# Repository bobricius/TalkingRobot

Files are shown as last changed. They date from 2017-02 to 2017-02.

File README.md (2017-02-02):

simple children toy robot 

Features 

- max. 44khz, 16bit wav 
- supply voltage 3,3V to 5V can be powered with LIR2032 battery, not CR2032! 
- you can optionally solder mini or micro usb connector 
- dimensions 5 cm x 10 cm 
- upgradeable firmware, AVR AtTiny861 based board 
- 16bit output created from 2 shifted 8bit PWM channels, good quality 
- output for speraker 
- can driving small speaker, amplifier is recommended 
- 8 control signals on header active in low 
- 8 buttons for testing + 2 LED on eyes, 1 LED as heart button (reset) + 8 LED connected to buttons 
- micro SD card push-push connector 

https://www.youtube.com/watch?v=AGjfrQgZr3E

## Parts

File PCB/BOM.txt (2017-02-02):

Partlist

Exported from robotrev2.brd at 2. 2. 2017 22:56

EAGLE Version 7.6.0 Copyright (c) 1988-2016 CadSoft

Assembly variant: 

Part          Value                   Package                 Library                       Position (mil)        Orientation

1                                     TACTILE-SWITCH-1101NE   SparkFun                      (1757.5 281.25)       R180
2                                     TACTILE-SWITCH-1101NE   SparkFun                      (507.5 275)           R180
3                                     TACTILE-SWITCH-1101NE   SparkFun                      (1457.5 1013.75)      R135
3V3           3V3                     SOT23                   okie                          (1145 962.5)          R180
4                                     TACTILE-SWITCH-1101NE   SparkFun                      (807.5 1012.5)        R45
5                                     TACTILE-SWITCH-1101NE   SparkFun                      (1863.75 1837.5)      R270
6                                     TACTILE-SWITCH-1101NE   SparkFun                      (395 1837.5)          R270
7                                     TACTILE-SWITCH-1101NE   SparkFun                      (1757.5 2631.25)      R315
8                                     TACTILE-SWITCH-1101NE   SparkFun                      (507.5 2637.5)        R45
BATTERY                               BATTCOM_20MM_PTH        es                            (1130 2895)           R270
BATTERYENABLE SOLDERJUMPERNO          SJ_2S-NO                SparkFun                      (730 2590)            R180
C1            10uF                    C0603                   rc-master-smd                 (740 2690)            R180
C2            100                     153CLV-0605             resistor                      (1128.75 3808.75)     R270
C3            10uF                    C0603                   rc-master-smd                 (1030 2870)           R270
C4            100n                    C0603                   rc-master-smd                 (1282.5 981.25)       R90
C5            100n                    C0603                   rc-master-smd                 (1001.25 975)         R270
C6            100n                    C0603                   rc-master-smd                 (1410 1595)           R270
C7            100n                    C0603                   rc-master-smd                 (855 1595)            R90
CHARGER                               SML0603                 led                           (920 2850)            R0
IC1           74HCT14D                SO14                    74xx-eu                       (1129 3430)           R180
IC2           MCP73831                SOT23-5                 SparkFunNew                   (745 2825)            R90
JP1                                   1X02                    pinhead                       (1470 2000)           MR270
JP2                                   1X02                    pinhead                       (795 1995)            R270
JP3                                   1X09                    pinhead                       (1130 1595)           MR270
JP5                                   1X02                    pinhead                       (620 3650)            R90
JP6                                   1X02                    pinhead                       (1645 3650)           R270
L1                                    SML0603                 led                           (1595 450)            R0
L2                                    SML0603                 led                           (670 450)             R0
L3                                    SML0603                 led                           (2020 250)            R0
L4                                    SML0603                 led                           (245 250)             R0
L5                                    SML0603                 led                           (1745 1425)           R0
L6                                    SML0603                 led                           (520 1425)            R0
L7                                    SML0603                 led                           (1995 1425)           R0
L8                                    SML0603                 led                           (270 1425)            R0
LEDCH         1k                      R0603                   rcl                           (905 2790)            R180
PB1                                   SML0603                 led                           (1391.25 3793.75)     R0
PB3                                   SML0603                 led                           (885 3800)            R0
PLAY2                                 SML0603                 led                           (1130 2820)           R0
R1            1k                      R0603                   resistor                      (1470 2650)           R270
R2            1k                      R0603                   resistor                      (1391.25 3925)        R180
R3            1k                      R0603                   resistor                      (1695 450)            R90
R4            1k                      R0603                   resistor                      (885 3925)            R0
R5            1k                      R0603                   resistor                      (570 450)             R90
R6            256k                    R0603                   resistor                      (1424 3425)           R45
R7            1k                      R0603                   resistor                      (1770 450)            R90
R8            1k                      R0603                   resistor                      (495 450)             R90
R9            1k                      R0603                   resistor                      (1745 1550)           R90
R10           1k                      R0603                   resistor                      (520 1550)            R90
R11           1k                      R0603                   resistor                      (1995 1550)           R90
R12           1k                      R0603                   resistor                      (270 1550)            R90
R13           1k                      R0603                   resistor                      (1389 3510)           R45
R14           200                     R0603                   resistor                      (824 3425)            R135
R15           56                      R0603                   resistor                      (859 3510)            R315
RPROG         22K                     R0603                   rcl                           (595 2825)            R0
S1            SWITCH-MOMENTARY-LEDPTH TACTILE-PTH-LED-12MM    Local Library                 (1130 2495)           R90
U$1           AVR_SPI_PRG_6NS         2X3-NS                  SparkFun                      (1132.75 2488.75)     MR180
U$3           MOUNTINGHOLE2.0         MOUNTINGHOLE_2.0_PLATED microbuilder                  (1901.25 2125)        R0
U$4           MOUNTINGHOLE2.0         MOUNTINGHOLE_2.0_PLATED microbuilder                  (363.75 2125)         R0
U$6           MOUNTINGHOLE2.0         MOUNTINGHOLE_2.0_PLATED microbuilder                  (588.75 706.25)       R0
U$7           MOUNTINGHOLE2.0         MOUNTINGHOLE_2.0_PLATED microbuilder                  (1676.25 706.25)      R0
U$9           MICROSD_PP              MICROSD_PP              DE1594-v2                     (1114.75 3326.5)      MR90
U1            ATTINY861A-SU           SOIC127P1032X265-20N    Atmel_By_element14_Batch_1-00 (1131.25 1595)        R0
USB1          USB-MICROBLARGEPAD      USB-MICROB_LARGEPAD     zak                           (1773 2665)           MR225
X5            USBSMD                  USB-MINIB               SparkFun                      (520 2595)            MR223

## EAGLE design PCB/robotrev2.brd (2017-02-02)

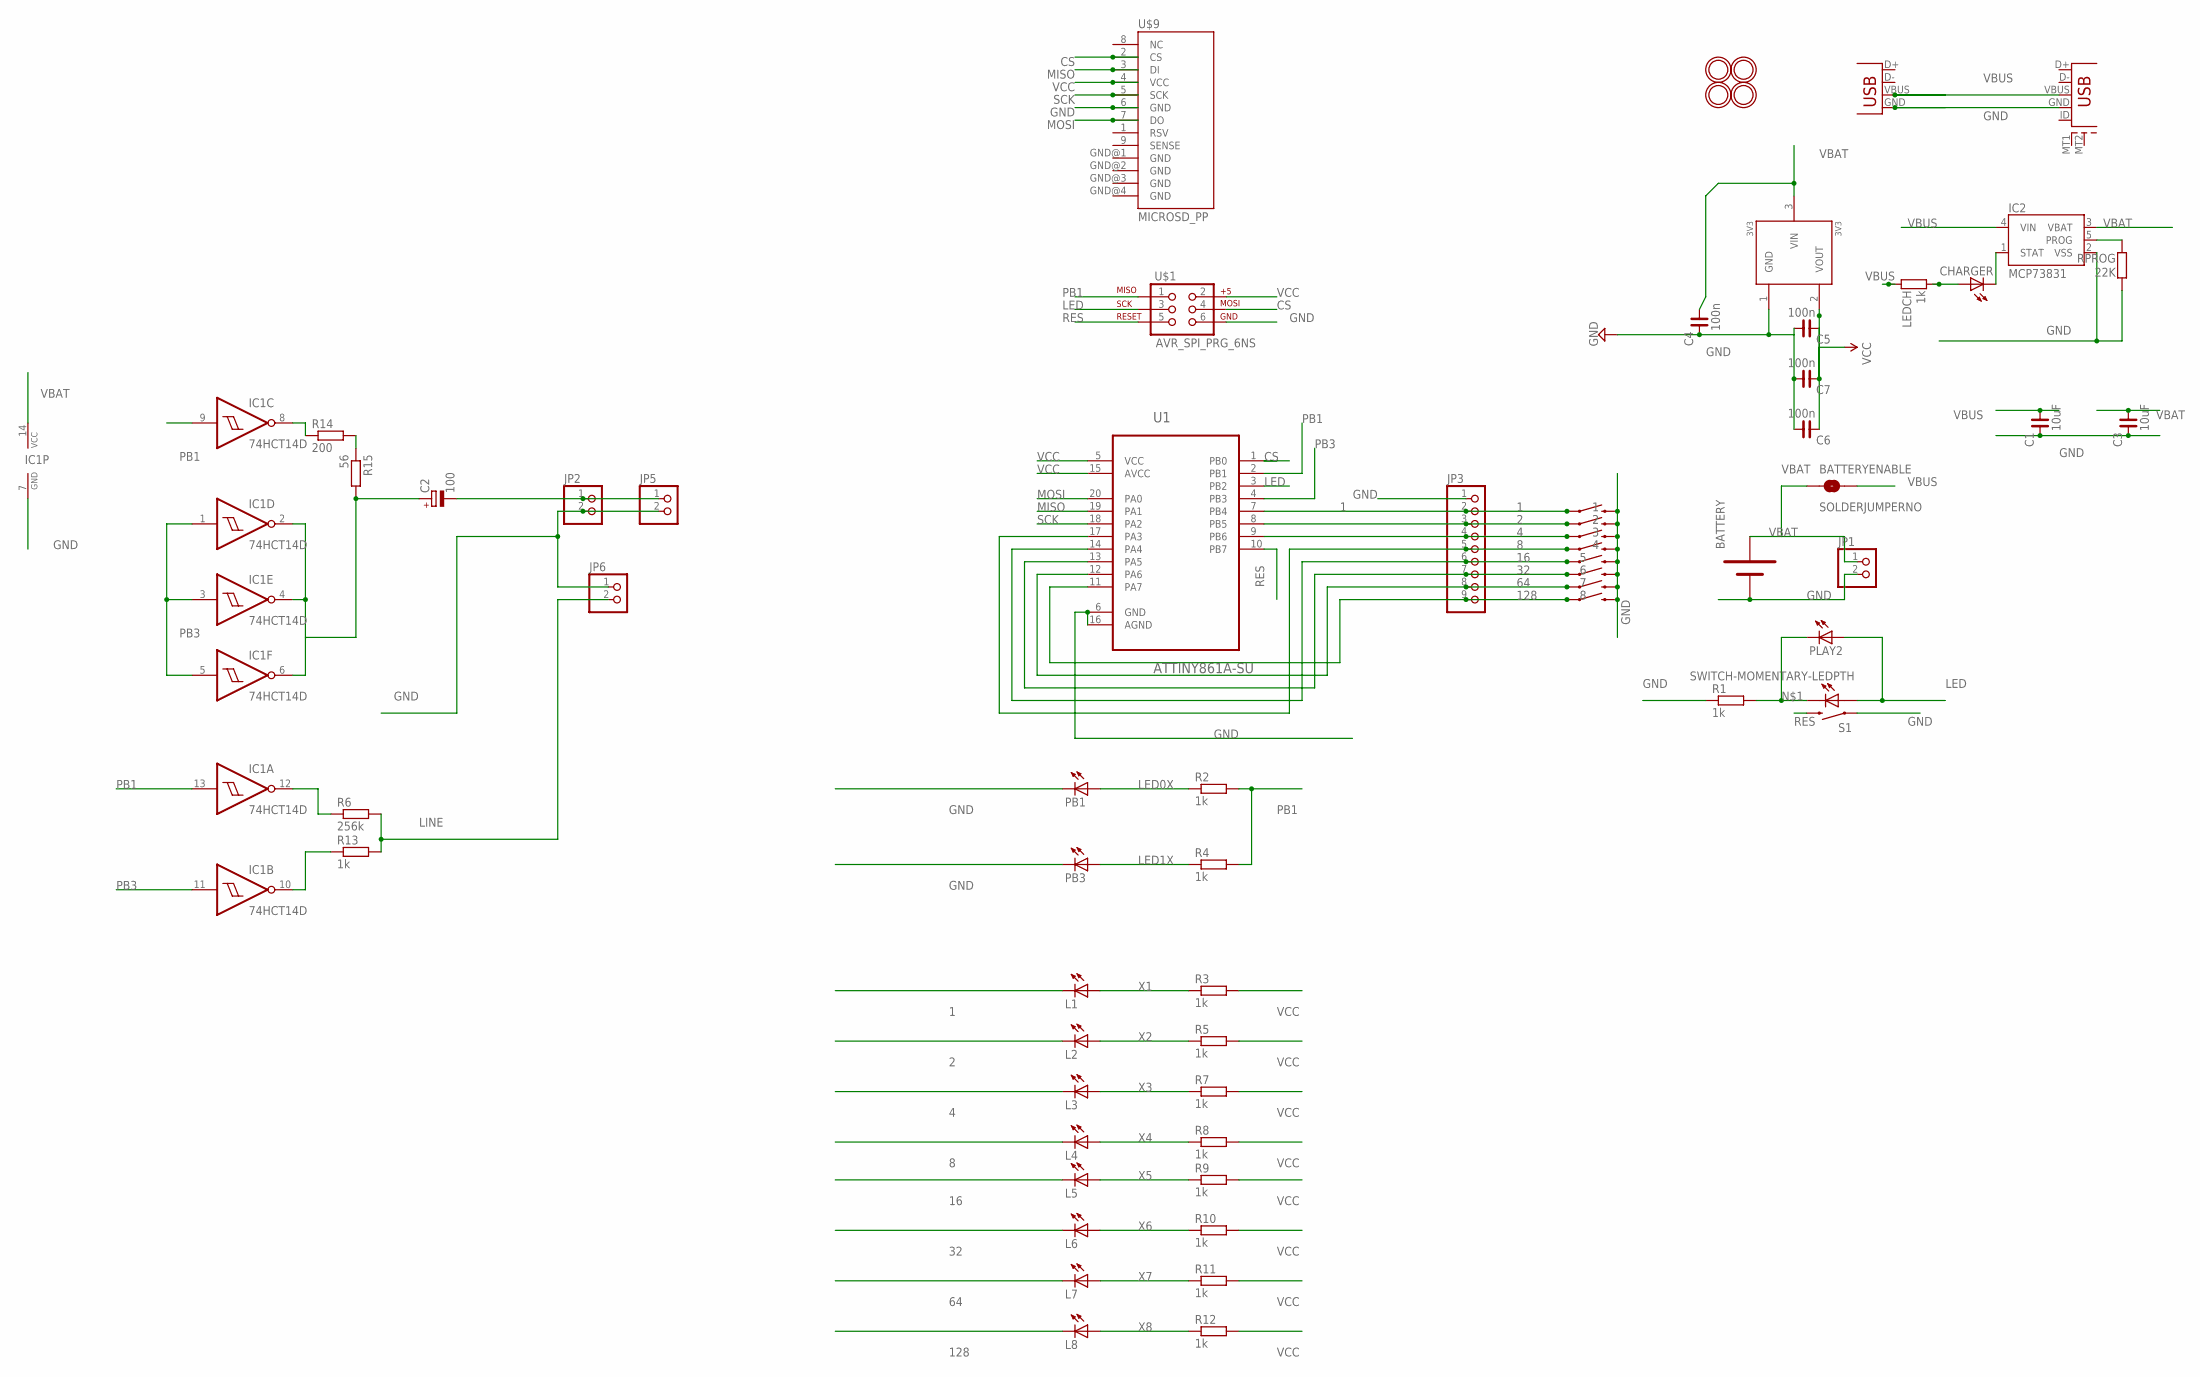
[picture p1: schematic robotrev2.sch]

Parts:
1, 2, 3, 4, 5, 6, 7, 8: SWITCH-MOMENTARY-2-SMD-1101NE; TACTILE-SWITCH-1101NE
3V3: 3V3; SOT23
BATTERY: BATTERY-1XAA20MM; BATTCOM_20MM_PTH
BATTERYENABLE: SOLDERJUMPERNO; SJ_2S-NO
C1, C3: 10uF; C0603
C2: 100; 153CLV-0605
C4, C5, C6, C7: 100n; C0603
CHARGER: LEDSML0603; SML0603
IC1: 74HCT14D; SO14
IC2: MCP73831; SOT23-5
JP1, JP2, JP5, JP6: PINHD-1X2; 1X02
JP3: PINHD-1X9; 1X09
L1, L2, L3, L4, L5, L6, L7, L8: LEDSML0603; SML0603
LEDCH: 1k; R0603
PB1, PB3: LEDSML0603; SML0603
PLAY2: LEDSML0603; SML0603
R1, R2, R3, R4, R5, R7, R8, R9, R10, R11, R12, R13: 1k; R0603
R6: 256k; R0603
R14: 200; R0603
R15: 56; R0603
RPROG: 22K; R0603
S1: SWITCH-MOMENTARY-LEDPTH; TACTILE-PTH-LED-12MM
U1: ATTINY861A-SU; SOIC127P1032X265-20N
U$1: AVR_SPI_PRG_6NS; 2X3-NS
U$3, U$4, U$6, U$7: MOUNTINGHOLE2.0; MOUNTINGHOLE_2.0_PLATED
U$9: MICROSD_PP
USB1: USB-MICROBLARGEPAD; USB-MICROB_LARGEPAD
X5: USBSMD; USB-MINIB

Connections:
1: 1.P$1 (1), JP3.2, L1.C, U1.7 (PB4)
2: 2.P$1 (1), JP3.3, L2.C, U1.8 (PB5)
4: 3.P$1 (1), JP3.4, L3.C, U1.9 (PB6)
8: 4.P$1 (1), JP3.5, L4.C, U1.17 (PA3)
16: 5.P$1 (1), JP3.6, L5.C, U1.14 (PA4)
32: 6.P$1 (1), JP3.7, L6.C, U1.13 (PA5)
64: 7.P$1 (1), JP3.8, L7.C, U1.12 (PA6)
128: 8.P$1 (1), JP3.9, L8.C, U1.11 (PA7)
CS: U1.1 (PB0), U$1.4, U$9.2 (CS)
GND: 1.P$2 (2), 2.P$2 (2), 3.P$2 (2), 3V3.1 (GND), 4.P$2 (2), 5.P$2 (2), 6.P$2 (2), 7.P$2 (2), 8.P$2 (2), BATTERY.-, C1.2, C3.2, C4.2, C5.1, C6.1, C7.1, IC1.7 (GND), IC2.2 (VSS), JP1.2, JP2.2, JP3.1, JP5.2, JP6.1, PB1.C, PB3.C, R1.1, RPROG.1, S1.4 (1), U1.6 (GND), U1.16 (AGND), U$1.6, U$9.6 (GND), USB1.GND, X5.GND
LED: PLAY2.A, S1.A, U1.3 (PB2), U$1.3
LED0X: PB1.A, R2.1
LED1X: PB3.A, R4.1
LINE: JP6.2, R6.2, R13.2
MISO: U1.19 (PA1), U$9.3 (DI)
MOSI: U1.20 (PA0), U$9.7 (DO)
unnamed: PLAY2.C, R1.2, S1.C
unnamed: IC1.8 (O), R14.1
unnamed: C2.+, IC1.2 (O), IC1.4 (O), IC1.6 (O), R15.2
unnamed: C2.-, JP2.1, JP5.1
unnamed: IC1.12 (O), R6.1
unnamed: IC1.10 (O), R13.1
unnamed: R14.2, R15.1
unnamed: CHARGER.C, IC2.1 (STAT)
unnamed: IC2.5 (PROG), RPROG.2
unnamed: CHARGER.A, LEDCH.1
PB1: IC1.9 (I), IC1.13 (I), R2.2, R4.2, U1.2 (PB1), U$1.1
PB3: IC1.1 (I), IC1.3 (I), IC1.5 (I), IC1.11 (I), U1.4 (PB3)
RES: S1.2, U1.10 (PB7), U$1.5
SCK: U1.18 (PA2), U$9.5 (SCK)
VBAT: 3V3.3 (VIN), BATTERY.+, BATTERYENABLE.1, C3.1, C4.1, IC1.14 (VCC), IC2.3 (VBAT), JP1.1
VBUS: BATTERYENABLE.2, C1.1, IC2.4 (VIN), LEDCH.2, USB1.VBUS, X5.VBUS
VCC: 3V3.2 (VOUT), C5.2, C6.2, C7.2, R3.2, R5.2, R7.2, R8.2, R9.2, R10.2, R11.2, R12.2, U1.5 (VCC), U1.15 (AVCC), U$1.2, U$9.4 (VCC)
X1: L1.A, R3.1
X2: L2.A, R5.1
X3: L3.A, R7.1
X4: L4.A, R8.1
X5: L5.A, R9.1
X6: L6.A, R10.1
X7: L7.A, R11.1
X8: L8.A, R12.1

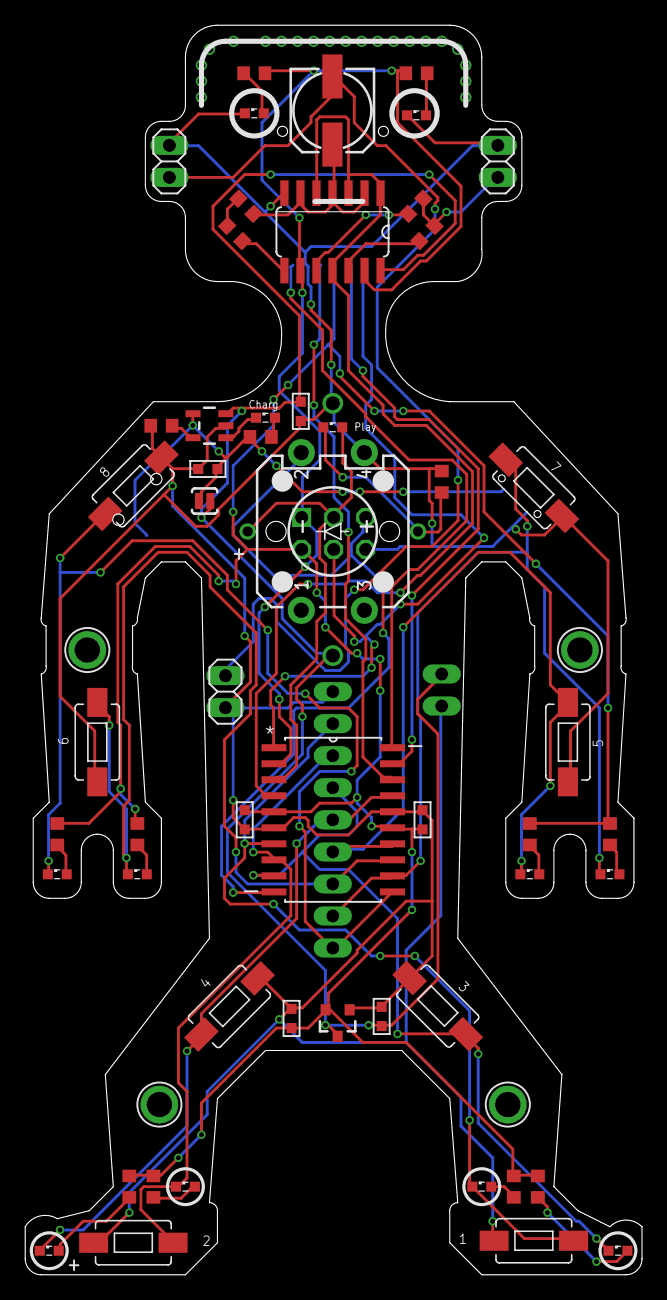
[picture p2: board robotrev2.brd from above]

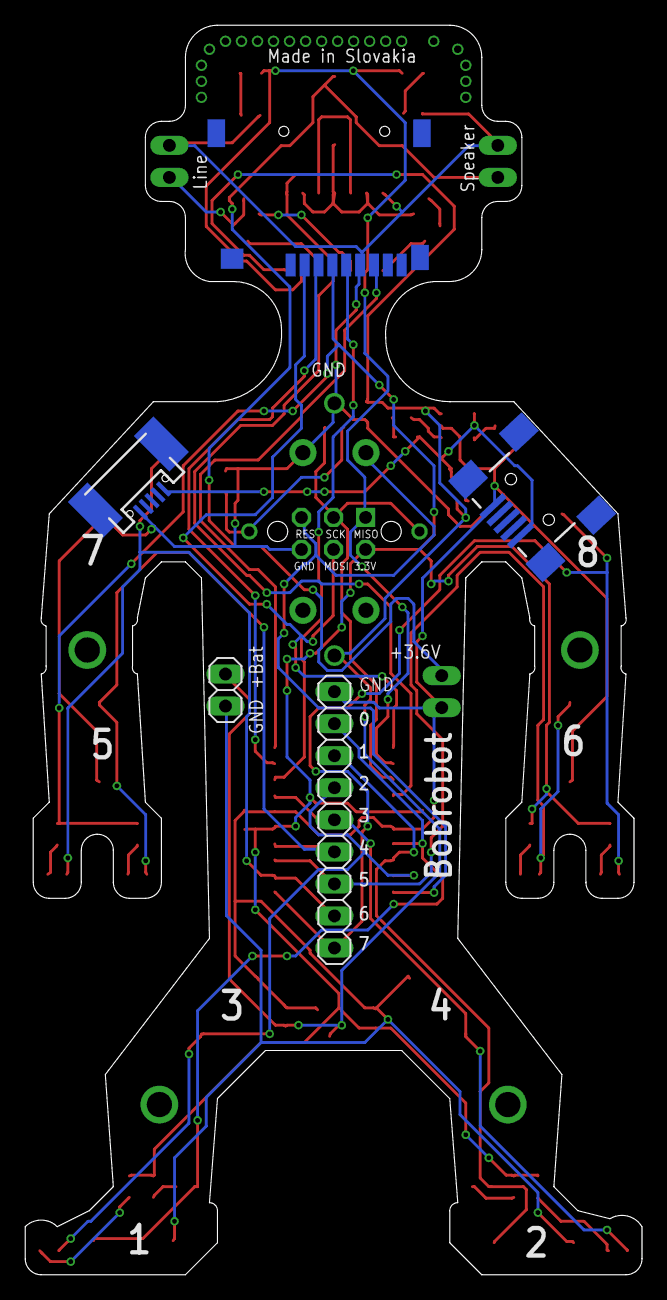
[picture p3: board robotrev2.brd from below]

Board: 2 copper layers, 48.9 x 99.1 mm, 64 parts (6 on the bottom side), 41 nets.

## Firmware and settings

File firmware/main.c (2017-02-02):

/*----------------------------------------------------------------------------/
/  20-pin SD Sound Generator R0.01a                                           /
/-----------------------------------------------------------------------------/
/ This project, program codes and circuit diagrams, is opened under license
/ policy of following trems.
/
/  Copyright (C) 2013, ChaN, all right reserved.
/
/ * This project is a free software and there is NO WARRANTY.
/ * No restriction on use. You can use, modify and redistribute it for
/   personal, non-profit or commercial products UNDER YOUR RESPONSIBILITY.
/ * Redistributions of source code must retain the above copyright notice.
/
/----------------------------------------------------------------------------*/

#include <avr/io.h>
#include <avr/interrupt.h>
#include <avr/pgmspace.h>
#include <avr/sleep.h>
#include <avr/wdt.h>
#include "pff.h"

#ifndef MODE
#error Wrong make file.
#endif

FUSES = {0xC1, 0xDD, 0xFF};	/* ATtiny861 fuse bytes: Low, High, Extended.
This is the fuse settings of this project. The fuse data will be included
in the output hex file with program code. However some old flash programmers
cannot load the fuse bits from hex file. If it is the case, remove this line
and use these values to program the fuse bits. */

#define FCC(c1,c2,c3,c4)	(((DWORD)c4<<24)+((DWORD)c3<<16)+((WORD)c2<<8)+(BYTE)c1)	/* FourCC */

#define LED_ON()	PORTB |= _BV(2)
#define LED_OFF()	PORTB &= ~_BV(2)

void delay_ms (WORD);	/* Defined in asmfunc.S */
void delay_us (WORD);	/* Defined in asmfunc.S */

EMPTY_INTERRUPT(PCINT_vect);


/*---------------------------------------------------------*/
/* Work Area                                               */
/*---------------------------------------------------------*/

volatile BYTE FifoRi, FifoWi, FifoCt;	/* FIFO controls */
BYTE Buff[256];		/* Audio output FIFO */

BYTE InMode, Cmd;	/* Input mode and received command value */

FATFS Fs;			/* File system object */
DIR Dir;			/* Directory object */
FILINFO Fno;		/* File information */

WORD rb;			/* Return value. Put this here to avoid avr-gcc's bug */



/*---------------------------------------------------------*/
/* Sub-routines                                            */
/*---------------------------------------------------------*/


static
void led_sign (
	BYTE ct		/* Number of flashes */
)
{
	do {
		delay_ms(200);
		LED_ON();
		delay_ms(100);
		LED_OFF();
	} while (--ct);
	delay_ms(1000);
}



static
BYTE chk_input (void)	/* 0:Not changed, 1:Changed */
{
	BYTE k, n;
	static BYTE pk, nk;


	wdt_reset();

	k = ~((PINA & 0xF8) | ((PINB >> 4) & 0x07));
	GIFR = _BV(PCIF);
	n = nk; nk = k;
	if (n != k || pk == k) return 0;

	pk = k; Cmd = k;

	return 1;
}



static
void ramp (		/* Ramp-up/down audio output (anti-pop feature) */
	int dir		/* 0:Ramp-down, 1:Ramp-up */
)
{
#if MODE != 0	/* This function is enebled on non-OCL output cfg. */
	BYTE v, d, n;


	if (dir) {
		v = 0; d = 1;
	} else {
		v = 128; d = 0xFF;
	}

	n = 128;
	do {
		v += d;
		OCR1A = v; OCR1B = v;
		delay_us(100);
	} while (--n);
#endif
}



static
void audio_on (void)	/* Enable audio output functions */
{
	if (!TCCR0B) {
		FifoCt = 0; FifoRi = 0; FifoWi = 0;		/* Reset audio FIFO */
		PLLCSR = 0b00000110;	/* Select PLL clock for TC1.ck */
		TCCR1A = 0b10100011;	/* Start TC1 with OC1A/OC1B PWM enabled */
		TCCR1B = 0b00000001;
		ramp(1);				/* Ramp-up to center level */
		TCCR0A = 0b00000001;	/* Enable TC0.ck = 2MHz as interval timer */
		TCCR0B = 0b00000010;
		TIMSK = _BV(OCIE0A);
	}
}



static
void audio_off (void)	/* Disable audio output functions */
{
	if (TCCR0B) {
		TCCR0B = 0;				/* Stop audio timer */
		ramp(0);				/* Ramp-down to GND level */
		TCCR1A = 0;	TCCR1B = 0;	/* Stop PWM */
	}
}



static
void wait_status (void)	/* Wait for a code change */
{
	BYTE n;


	if (Cmd) return;

	audio_off();	/* Disable audio output */

	for (;;) {
		n = 10;				/* Wait for a code change at active mode (100ms max) */
		do {
			delay_ms(10);
			chk_input();
		} while (--n && !Cmd);
		if (Cmd) break;		/* Return if any code change is detected within 100ms */

		cli();							/* Enable pin change interrupt */
		GIMSK = _BV(PCIE1);
		WDTCR = _BV(WDE) | _BV(WDCE);	/* Disable WDT */
		WDTCR = 0;
		sleep_enable();					/* Wait for a code change at power-down mode */
		sei();
		sleep_cpu();
		sleep_disable();
		wdt_reset();					/* Enable WDT (1s) */
		WDTCR = _BV(WDE) | 0b110;
		GIMSK = 0;						/* Disable pin change interrupt */
	}
}



static
DWORD load_header (void)	/* 2:I/O error, 4:Invalid file, >=1024:Ok(number of samples) */
{
	DWORD sz, f;
	BYTE b, al = 0;


	/* Check RIFF-WAVE file header */
	if (pf_read(Buff, 12, &rb)) return 2;
	if (rb != 12 || LD_DWORD(Buff+8) != FCC('W','A','V','E')) return 4;

	for (;;) {
		if (pf_read(Buff, 8, &rb)) return 2;		/* Get Chunk ID and size */
		if (rb != 8) return 4;
		sz = LD_DWORD(&Buff[4]);		/* Chunk size */

		switch (LD_DWORD(&Buff[0])) {	/* Switch by chunk type */
		case FCC('f','m','t',' ') :		/* 'fmt ' chunk */
			if (sz & 1) sz++;
			if (sz > 128 || sz < 16) return 4;		/* Check chunk size */
			if (pf_read(Buff, sz, &rb)) return 2;	/* Get the chunk content */
			if (rb != sz) return 4;
			if (Buff[0] != 1) return 4;				/* Check coding type (1: LPCM) */
			b = Buff[2];
			if (b < 1 && b > 2) return 4; 			/* Check channels (1/2: Mono/Stereo) */
			GPIOR0 = al = b;						/* Save channel flag */
			b = Buff[14];
			if (b != 8 && b != 16) return 4;		/* Check resolution (8/16 bit) */
			GPIOR0 |= b;							/* Save resolution flag */
			if (b & 16) al <<= 1;
			f = LD_DWORD(&Buff[4]);					/* Check sampling freqency (8k-48k) */
			if (f < 8000 || f > 48000) return 4;
			OCR0A = (BYTE)(16000000UL/8/f) - 1;		/* Set interval timer (sampling period) */
			break;

		case FCC('d','a','t','a') :		/* 'data' chunk (start to play) */
			if (!al) return 4;							/* Check if format valid */
			if (sz < 1024 || (sz & (al - 1))) return 4;	/* Check size */
			if (Fs.fptr & (al - 1)) return 4;			/* Check offset */
			return sz;

		case FCC('D','I','S','P') :		/* 'DISP' chunk (skip) */
		case FCC('f','a','c','t') :		/* 'fact' chunk (skip) */
		case FCC('L','I','S','T') :		/* 'LIST' chunk (skip) */
			if (sz & 1) sz++;
			if (pf_lseek(Fs.fptr + sz)) return 2;
			break;

		default :						/* Unknown chunk */
			return 4;
		}
	}
}



static
BYTE play (		/* 0:Normal end, 1:Continue to play, 2:Disk error, 3:No file, 4:Invalid file */
	BYTE fn		/* File number (1..255) */
)
{
	DWORD sz, spa, sza;
	FRESULT res;
	WORD btr;
	BYTE n, i, rc;


	if (InMode >= 2) Cmd = 0;	/* Clear command code (Edge triggered) */

	/* Open an audio file "nnn.WAV" (nnn=001..255) */
	i = 2; n = fn;
	do {
		Buff[i] = (BYTE)(n % 10) + '0'; n /= 10;
	} while (i--);
	strcpy_P((char*)&Buff[3], PSTR(".WAV"));
	res = pf_open((char*)Buff);
	if (res == FR_NO_FILE) return 3;
	if (res != FR_OK) return 2;

	/* Get file parameters */
	sz = load_header();
	if (sz <= 4) return (BYTE)sz;	/* Invalid format */
	spa = Fs.fptr; sza = sz;		/* Save offset and size of audio data */

	LED_ON();
	audio_on();		/* Enable audio output */

	for (;;) {
		if (pf_read(0, 512 - (Fs.fptr % 512), &rb) != FR_OK) {		/* Snip sector unaligned part */
			rc = 2; break;
		}
		sz -= rb;
		do {
			/* Forward a bunch of the audio data to the FIFO */
			btr = (sz > 1024) ? 1024 : (WORD)sz;
			pf_read(0, btr, &rb);
			if (btr != rb) {
				rc = 2; break;
			}
			sz -= rb;

			/* Check input code change */
			rc = 0;
			if (chk_input()) {
				switch (InMode) {
				case 4:		/* Mode 4: Edge triggered (one-shot) */
					if (!Cmd) rc = 1;
					break;
				case 3: 	/* Mode 3: Edge triggered (retriggerable) */
					if (Cmd) rc = 1;	/* Restart by a code change but zero */
					break;
				case 2:		/* Mode 2: Edge triggered */
					Cmd = 0;			/* Ignore code changes while playing */
					break;
				case 1:		/* Mode 1: Level triggered (sustained to end of the file) */
					if (Cmd && Cmd != fn) rc = 1;	/* Restart by a code change but zero */
					break;
				case 0:	/* Mode 0: Level triggered */
					if (Cmd != fn) rc = 1;	/* Restart by a code change */
				}
			}
		} while (!rc && rb == 1024);	/* Repeat until all data read or code change */

		if (rc || !Cmd || InMode >= 2) break;
		if (pf_lseek(spa) != FR_OK) {	/* Return top of audio data */
			rc = 3; break;
		}
		sz = sza;
	}

	while (FifoCt) ;			/* Wait for audio FIFO empty */
	OCR1A = 0x80; OCR1B = 0x80;	/* Return DAC out to center */

	LED_OFF();

	return rc;
}



/*-----------------------------------------------------------------------*/
/* Main                                                                  */

int main (void)
{
	BYTE rc;


	MCUSR = 0;								/* Clear reset status */
	WDTCR = _BV(WDE) | 0b110;				/* Enable WDT (1s) */
	set_sleep_mode(SLEEP_MODE_PWR_DOWN);	/* Select power down mode for sleep */
	PCMSK0 = 0b11111000;					/* Select pin change interrupt pins (SW1..SW8) */
	PCMSK1 = 0b01110000;

	/* Initialize ports */
	PORTA = 0b11111011;		/* PORTA [pppppLHp]*/
	DDRA  = 0b00000110;
	PORTB = 0b01110001;		/* PORTB [-pppLLLH] */
	DDRB  = 0b00001111;

	sei();

	for (;;) {
		if (pf_mount(&Fs) == FR_OK) {	/* Initialize FS */

			/* Load command input mode (if not exist, use mode 0 as default) */
			strcpy_P((char*)Buff, PSTR("000.TXT"));
			if (pf_open((char*)Buff) == FR_OK) {
				pf_read(&InMode, 1, &rb);
				InMode -= '0';
			}

			/* Main loop */
			do {
				wait_status();				/* Wait for any valid code */
				rc = play(Cmd);				/* Play corresponding audio file */
				if (rc >= 2) led_sign(rc);	/* Display if any error occured */
				if (rc != 1) Cmd = 0;		/* Clear code when normal end or error */
			} while (rc != 2);				/* Continue while no disk error */

			audio_off();	/* Disable audio output */
		}
		led_sign(2);	/* Disk error or Media mount failed */
	}
}
